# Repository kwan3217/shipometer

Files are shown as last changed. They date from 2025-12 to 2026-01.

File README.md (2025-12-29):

# Ansible for Shipometer

## Before first boot

Use `rpi-imager`. 

### Older `rpi-image` (<2.0.3)

1. Get an image that does Debian 12 (Bookworm) not Debian 13 (Trixie)
    * Raspberry Pi OS (Other) -> Raspberry Pi OS (Legacy, 64-bit) Lite
2. Eject MicroSD card from fluttershy and insert it in SD card reader attached to Celestia. 
3. Edit settings
    * General
      * [x] Set Hostname: `fluttershy`.local
      * [x] Set username and password:
         * Username: `chrisj`
         * Password: ******
      * [ ] Configure wireless LAN
      * [x] Set locale settings:
         * Time Zone: `America/Chicago` or as appropriate 
         * Keyboard layout: `us`
    * Services
       * [x] Enable SSH
          * ( ) Use password authentication
          * (*) Allow public-key authentication only
             * Set authorized_keys for `chrisj`: `<copy and paste from first line of /home/chrisj/.ssh/id_rsa.pub>` 
    * Options
      * [ ] Play sound when finished
      * [x] Eject media when finished
      * [ ] Enable telemetry

### Newer `rpi-image` (2.0.3)
1. Select the device type -- Raspberry Pi 5 for the current `fluttershy`
2. Raspberry Pi OS (Other) -> Raspberry Pi OS (Legacy, 64-bit) Lite
3. Insert and select the correct medium -- it is often already mounted
   as `/media/chrisj/devicename`. It is CRITICALLY IMPORTANT to get this right 
   -- check that the file size matches what is expected, and that it isn't
   one of your existing drives on the host filesystem. The check box [x] Exclude System Drives
   helps with this.
4. Set the hostname `fluttershy` not `fluttershy.local` or `fluttershy.kwansystems.org`
5. Set the capital city, time zone, and keyboard layout.
6. Set the user name `chrisj` and the password `<SECRET>`
7. Skip wifi for now
8. Enable SSH
   * ( ) Use Password Authentication
   * (*) Use public key authentication
      * Set authorized_keys for `chrisj`: `<copy and paste from first line of /home/chrisj/.ssh/id_rsa.pub>` 

### Write the image
Continue until the program writes the image on the card. Writing the image will take a few minutes.

## Boot new card in Fluttershy
Unmount and remove the card from the host and install it in a powered-off or red light Raspberry Pi 5.
Start it back up and wait for it to respond to pings. The router (Megumi)
knows Fluttershy's MAC address and will assign it the known IP `192.168.217.102`
and name `fluttershy.kwansystems.org`

## Run ansible
```
cd shipometer/ansible
ansible-playbook -i inventory.ini playbook.yml
```

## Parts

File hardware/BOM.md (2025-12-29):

# Shipometer Hardware Bill of Materials

| Qty | Description | Part Number / Spec | Notes / Link | Approx. Unit Cost (bulk) |
|-----|---|---|---|---|
| 1 | Raspberry Pi 5 8GB | Raspberry Pi 5 | Official board - fluttershy | - |
| 1 | dAISy 2+ AIS USB receiver | dAISy 2+ | USB dongle, black aluminum enclosure typical | - |
| 1 | FlightAware Pro Stick Plus ADS-B receiver | FA-PROSTICKPLUS | Or equivalent USB dongle | - |
| 1 | Sparkfun breakout for u-blox ZED-F9R GPS module (with IMU) | ZED-F9R | UART + PPS wired to GPIO | Datasheet: https://www.u-blox.com/en/product/zed-f9r-module |
| 1 | Bosch BME280 sensor breakout | BME280 | SPI on GPIO | Datasheet: https://www.bosch-sensortec.com/products/environmental-sensors/humidity-sensors-bme280/ |
| 1 | Optional cooling fan (for enclosed case) | CoolCox CC3007H05S (or equiv.) | 30x30x7mm, 5V, 4-pin JST-SH 1.0mm pitch (PWM + tach), ~8000 RPM max, 2.79 CFM | Matches official Pi 5 case fan; Datasheet: https://www.coolcox.com/products/pdf/CC3007.pdf |
| 4 | M2.5 brass/hex standoffs (various lengths, e.g., 11mm + 20mm) | Generic M2.5 F/F or M/F | For Pi mounting + HAT spacing | Jellybean; e.g., from assortment kits |
| 8-16| M2.5 screws (e.g., 6-12mm pan head) | Generic M2.5 stainless | For securing board, lid, standoffs | - |
| 4 | Silicone feet or bumpers | Generic 8-10mm dia. | Anti-slip for desk/cabin mount | - |
| 1 | Custom 3D-printed case | Your OpenSCAD design | PLA/PETG/ABS recommended for durability | - |
| Misc| Antennas (GPS mushroom, 1090MHz ADS-B, 161-162MHz AIS) | Various | Roof-mounted when landlocked | - |
| Misc| Cables (USB extensions, UART jumpers, PPS wire) | - | As needed for clean routing | - |

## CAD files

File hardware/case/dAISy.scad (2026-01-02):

MM=1;
INCH=25.4*MM;



module daisy() {
  board_w=3.0*INCH;
  board_d=1.95*INCH;
  board_h=1.6*MM;
  module daisy_main_board() {
    hole_r=3.0*MM/2;
    // clearances between edge of hole and edge of board measured by outside caliper
    hole_x1=        2.5*MM;
    hole_x2=board_w-2.6*MM;
    hole_y1=        2.7*MM;
    hole_y2=board_d-2.0*MM;
    color("green")
    translate([0,0,-board_h])
    difference() {
      // substrate
      cube([board_w,board_d,board_h]);
      // mounting holes
      translate([hole_x1+hole_r,hole_y1+hole_r,-1*MM])
      cylinder(h=2*MM+board_h,r=hole_r,$fn=24);
      translate([hole_x2-hole_r,hole_y1+hole_r,-1*MM])
      cylinder(h=2*MM+board_h,r=hole_r,$fn=24);
      translate([hole_x1+hole_r,hole_y2-hole_r,-1*MM])
      cylinder(h=2*MM+board_h,r=hole_r,$fn=24);
      translate([hole_x2-hole_r,hole_y2-hole_r,-1*MM])
      cylinder(h=2*MM+board_h,r=hole_r,$fn=24);
    }
  }
  daisy_main_board();
  module bnc() {
    cube_w=14.5*MM;
    cube_d=14.5*MM;
    cube_h=17.1*MM-board_h;
    color("#c0c0c0")
    union() {
      cube([cube_w,cube_d,cube_h]);
      // thread
      thread_r=0.48*INCH/2;
      thread_d=23.2*MM-cube_d;
      thread_square=10.7*MM;
      intersection() {
        translate([cube_w/2,1*MM,15.3*MM-board_h-thread_r])
        rotate([90,0,0])
        cylinder(h=thread_d+1*MM,r=thread_r);
        translate([cube_w/2,1*MM,15.3*MM-board_h-thread_r])
        cube([thread_square,20*MM,thread_square],center=true);
      }
      // barrel
      barrel_r=0.37*INCH/2;
      barrel_d=35.2*MM-cube_d-thread_d;
      translate([cube_w/2,1*MM-thread_d,15.3*MM-board_h-thread_r])
      rotate([90,0,0])
      cylinder(h=barrel_d+1*MM,r=barrel_r);
    }
  }
  translate([55*MM,0.5*MM,0*MM])
  bnc();
}

daisy();

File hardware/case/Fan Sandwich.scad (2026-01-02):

include<kwan_primitives.scad>

EPS=0.5*MM;

M5_hole_MM=3.0;

module fan_sandwich_bottom_plate() {
difference() {
//main body
translate([0,0,0])
rounded_cube((58+7)*MM,56*MM,2*MM);

//corner holes
translate([3.5*MM,3.5*MM,-1*MM])
cylinder(5,M5_hole_MM/2,M5_hole_MM/2,$fn=24);
translate([(3.5+58)*MM,3.5*MM,-1])
cylinder(5,M5_hole_MM/2,M5_hole_MM/2,$fn=24);
translate([3.5,(3.5+49)*MM,-1])
cylinder(5,M5_hole_MM/2,M5_hole_MM/2,$fn=24);
translate([(3.5+58)*MM,(3.5+49)*MM,-1*MM])
cylinder(5,M5_hole_MM/2,M5_hole_MM/2,$fn=24);

//GPIO hole
translate([(3.5+29)*MM,(3.5+49)*MM,1*MM])
cube([2*INCH+EPS*2,0.2*INCH+EPS,4*MM],center=true);
translate([(3.5+29)*MM-1*INCH+15*MM,(56/2)*MM,-1])
cylinder(h=4*MM,r1=28/2*MM,r2=28/2*MM);
}
}

module fan_hook() {
  translate([-2*MM,-2.5*MM,-1*MM])
  difference(){
  cube([3*MM,5*MM,10*MM+EPS*2]);
  translate([2*MM,-1*MM,-1*MM])
  cube([5*MM,7*MM,9*MM+EPS*2]);
  color("blue")
  translate([0*MM,-1*MM,12*MM])
  rotate([0,45,0])
  cube([5*MM,7*MM,5*MM]);
  }
}

module fan_hole() {
translate([0,0,(7.7/2+1)*MM])
rotate([180,0,0])
union(){
cylinder(h=(7.7/2+1)*MM,r1=4.5*MM/2,r2=4.5*MM/2,$fn=24);
cylinder(h=(7.7+2)*MM,r1=3.2*MM/2,r2=3.2*MM/2,$fn=24);
}
}

module fan() {
  difference() {
    translate([-30.4/2*MM,-30.4/2*MM,-7.7/2*MM])
    rounded_cube(30.4*MM,30.4*MM,7.7*MM,r=3.2*MM);
    
    translate([0,0,-(7.7+1)/2*MM])
    cylinder(h=9.7*MM,r1=27/2*MM,r2=27/2*MM);

    translate([-12*MM,-12*MM,0])
    fan_hole();
    translate([12*MM,-12*MM,0])
    fan_hole();
    translate([-12*MM,12*MM,0])
    fan_hole();
    translate([12*MM,12*MM,0])
    fan_hole();
  }
}

module fan_pegs() {
    translate([-12*MM,-12*MM,-2*MM])
    cylinder(h=3*MM,r=(4*MM-EPS)/2,$fn=24);
    translate([12*MM,-12*MM,-2*MM])
    cylinder(h=3*MM,r=(4*MM-EPS)/2,$fn=24);
    translate([-12*MM,12*MM,-2*MM])
    cylinder(h=3*MM,r=(4*MM-EPS)/2,$fn=24);
    translate([12*MM,12*MM,-2*MM])
    cylinder(h=3*MM,r=(4*MM-EPS)/2,$fn=24);
}

module fan_sandwich() {
  union() {
  fan_sandwich_bottom_plate();

  translate([(3.5+29)*MM-1*INCH+15*MM,(56/2)*MM,0])color("orange")fan_pegs();
    translate([(3.5+29)*MM-1*INCH+15*MM,(56/2)*MM+15*MM,0])
    rotate([0,0,-90])
    rotate([180,0,0])
    fan_hook();
  }
}

module placed_fan() {
  translate([(3.5+29)*MM-1*INCH+15*MM,(56/2)*MM,-7.7/2*MM])
  color("black")
  fan();
}

// Uncomment this if you want to actually print it
//rotate([180,0,0]) fan_sandwich();

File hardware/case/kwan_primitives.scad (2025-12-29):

INCH=25.4; // multiply a measurement in inches by this to get mm
MM=1; // for completeness and readability


module rounded_cube(l,w,h,r=2*MM) {
  union() {
    translate([r,0,0])
    cube([l-2*r,w,h]);
    translate([0,2,0])
    cube([l,w-2*r,h]);
    translate([r,r,0])
    cylinder(h=h,r1=r,r2=r,$fn=36);
    translate([r,w-r,0])
    cylinder(h=h,r1=r,r2=r,$fn=36);
    translate([l-r,r,0])
    cylinder(h=h,r1=r,r2=r,$fn=36);
    translate([l-r,w-r,0])
    cylinder(h=h,r1=r,r2=r,$fn=36);
  }
}

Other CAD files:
hardware/case/ShipometerCase.scad
hardware/case/test_nut.scad
hardware/case/zed-f9r.scad
hardware/case/zed_f9r_case.scad

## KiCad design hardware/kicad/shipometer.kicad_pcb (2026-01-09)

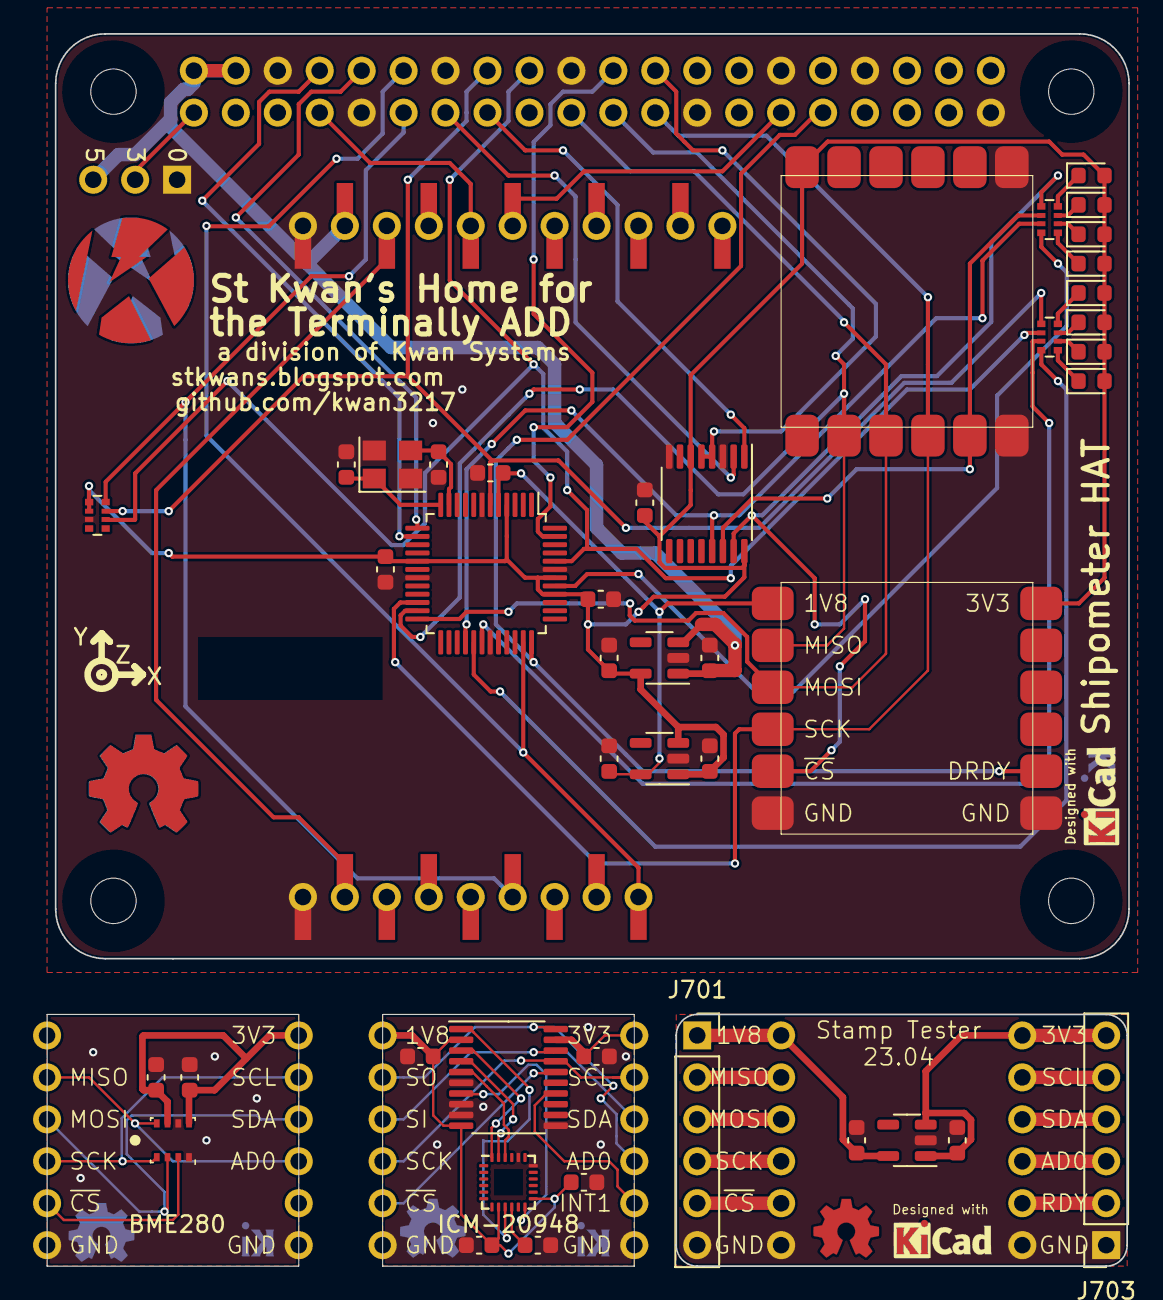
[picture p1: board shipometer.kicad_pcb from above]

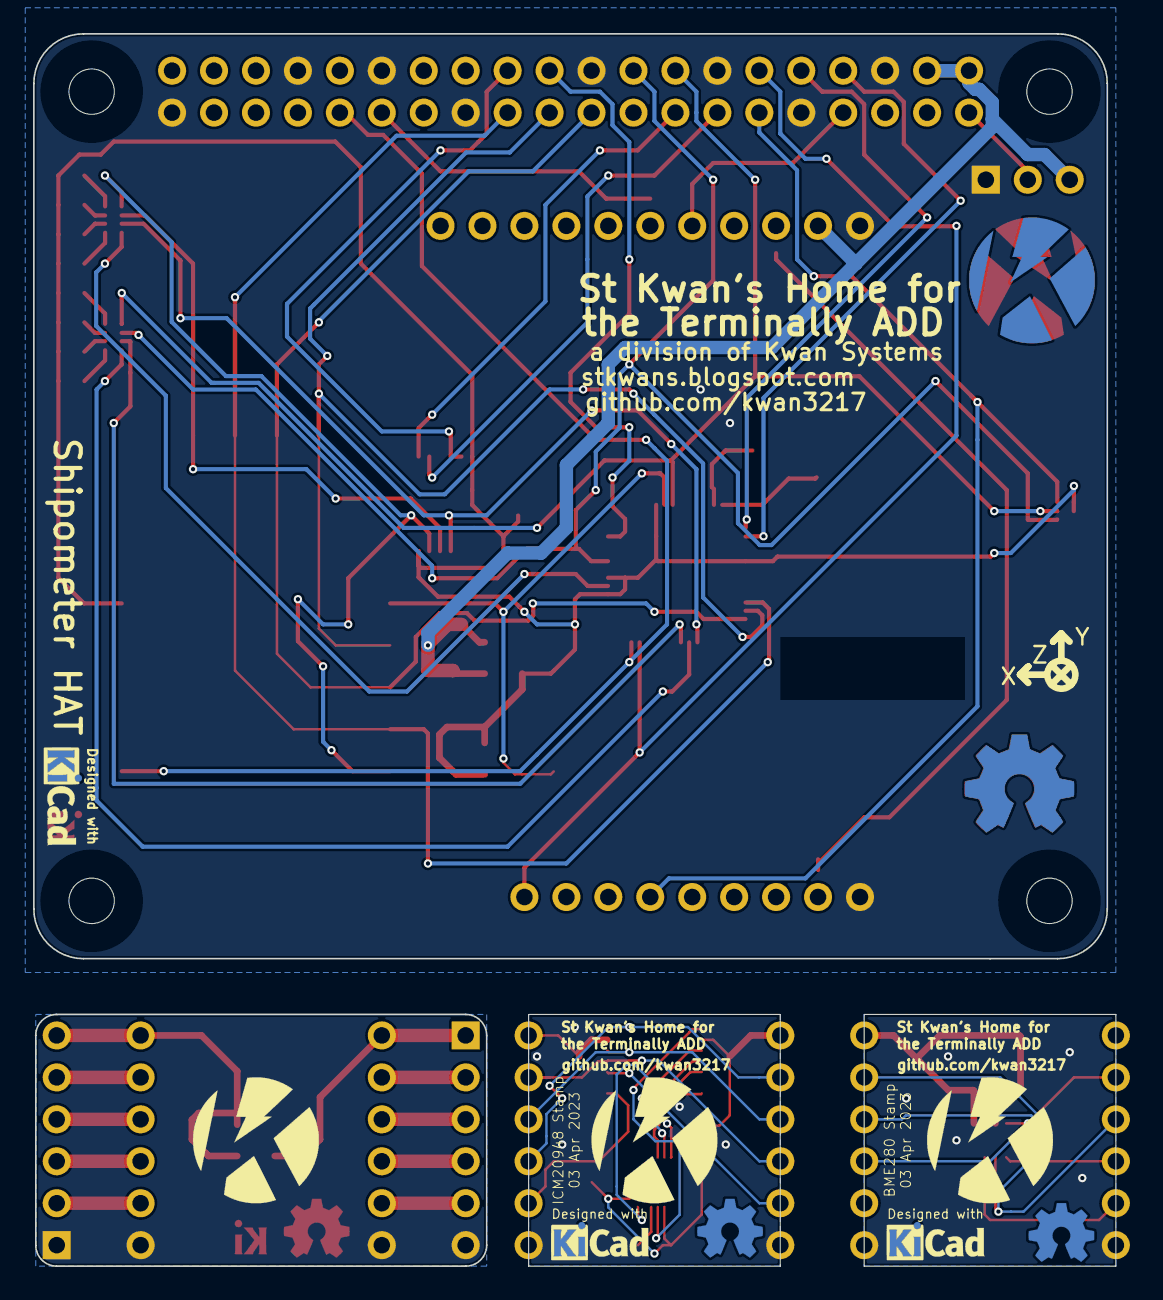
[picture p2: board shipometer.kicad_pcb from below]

Board: 2 copper layers, 65.5 x 74.6 mm, 66 parts (10 on the bottom side), 69 nets.

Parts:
C116, C206, C208, C401, C405, C501, C505, C605, C617, C640, C801, C805: 1uF; C_0603_1608Metric
C302, C308, C310, C313, C319: 100nF; C_0603_1608Metric
C611, C612: 22pF; C_0603_1608Metric
D101, D103, D104: White; LED_0603_1608Metric
D106: Blue; LED_0603_1608Metric
D129: Red; LED_0603_1608Metric
D130: Green; LED_0603_1608Metric
D141, D144: Yellow; LED_0603_1608Metric
G101: Axis
G102, G105: KwanSystems; StKwansSoldermask
G103, G107, G202, G302, G702: Designed with; Symbol_KiCAD-Logo_CopperAndSilkScreenTop_small
G104, G106: OSHW; OSHW-Symbol_6.7x6mm_SolderMask
G201, G301, G701: github.com/kwan3217; KWAN_CIRCLE
G203, G303, G703: OSHW; OSHW-Symbol_4x3.6mm_SolderMask
J101: Raspberry_Pi_40; PiHAT_NoSlot_Narrow
J102: Conn_01x03; PinHeader_1x03_P2.54mm_Horizontal
J104: ICM20948; StampPad
J105: BME280; StampPad
J106: ZED-F9R
J201, J301: Stamp
J701, J703: Conn_01x06_Pin; PinSocket_1x06_P2.54mm_Vertical
J702, J704: Conn_01x06_Pin; PinHeader_1x06_P2.54mm_Vertical
R101, R102: 330; R_Array_Convex_4x0402
R103: 10k; R_Array_Convex_4x0402
U102: 74LS138; TSSOP-16_4.4x5mm_P0.65mm
U201: BME280; Bosch_LGA-8_2.5x2.5mm_P0.65mm_ClockwisePinNumbering
U301: ICM-20948; InvenSense_QFN-24_3x3mm_P0.4mm
U302: TXS0108EPW; TSSOP-20_4.4x6.5mm_P0.65mm
U401: TCR2EF 3.3V; SOT-23-5
U501, U801: TCR2EF 1.8V; SOT-23-5
U601: LPC210x; LQFP-48_7x7mm_P0.5mm
Y601: 12MHz; Crystal_SMD_Abracon_ABM8G-4Pin_3.2x2.5mm

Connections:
3V3: J106.3 (3V3), J106.13 (3V3)
+1V8: C505.1, C605.1, J104.1 (1V8), U501.5 (OUT), U601.5 (VDD(1V8))
+3.3VP: J101.1 (3V3), J102.2
+3V3: C116.1, C405.1, C501.1, C617.1, C640.1, D101.2 (A), D103.2 (A), D104.2 (A), D106.2 (A), D129.2 (A), D130.2 (A), D141.2 (A), D144.2 (A), J104.12 (3V3), J105.12 (3V3), R103.1 (4), R103.2 (4), U102.6 (E3), U102.16 (VCC), U401.5 (OUT), U501.1 (IN), U501.3 (EN), U601.4 (VBAT), U601.17 (VDD(3V3)), U601.40 (VDD(3V3)), U601.42 (VDDA)
+5V: C401.1, J101.2 (5V), J101.4 (5V), J102.3, J106.2 (5V), U401.1 (IN), U401.3 (EN)
/BOOTSTRAP-: D144.1 (K), R102.7 (5)
/CS_A0: J101.15 (GPIO22_(GEN3)), U102.1 (A0)
/CS_A1: J101.13 (GPIO27_(GEN2)), U102.2 (A1)
/DRDY-: D129.1 (K), R102.5
/DRDY_6D: J101.31 (GPIO6), J104.8 (DRDY), U601.36 ((CTS1/CAP1.1/AD0.4)P0.11)
/DRDY_MAG: J101.22 (GPIO25_(GEN6)), U601.47 ((CAP1.2/SCL1)P0.17)
/DRDY_MAG-: D130.1 (K), R102.6 (5)
/GPS_RX: J101.7 ((TX3)_GPIO4), J106.5 (RX/MOSI)
/GPS_TX: J101.29 ((RX3)_GPIO5), J106.6 (TX/MISO)
/GPS_~RESET: J101.11 (GPIO17_(GEN0)), J106.17 (~RESET), R103.8 (5)
/IMU/INT1_1V8: U301.12 (INT1), U302.7 (A6)
/IMU/INT1_3V3: J301.8 (INT1), U302.14 (B6)
/IMU/MISO_1V8: U301.9 (SDO/AD0), U302.1 (A1)
/IMU/MISO_3V3: J301.2 (MISO), J301.9 (AD0), U302.20 (B1)
/IMU/MOSI_1V8: U301.24 (SDA/SDI), U302.3 (A2)
/IMU/MOSI_3V3: J301.3 (MOSI), J301.10 (SDA), U302.18 (B2)
/IMU/Q_1V8: C302.1, C308.1, C313.1, J301.1 (1V8), U301.8 (VDDIO), U301.13 (VDD), U302.2 (VCCA), U302.10 (OE)
/IMU/Q_3V3: C319.1, J301.12 (3V3), U302.19 (VCCB)
/IMU/Q_GND: C302.2, C308.2, C310.2, C313.2, C319.2, J301.6 (GND), J301.7 (GND), U301.18 (GND), U301.20 (GND), U302.6 (A5), U302.8 (A7), U302.9 (A8), U302.11 (GND)
/IMU/SCK_1V8: U301.23 (SCL/SCLK), U302.4 (A3)
/IMU/SCK_3V3: J301.4 (SCK), J301.11 (SCL), U302.17 (B3)
/IMU/~CS_1V8: U301.22 (~CS), U302.5 (A4)
/IMU/~CS_3V3: J301.5 (~CS), U302.16 (B4)
/LPC_RESET-: D106.1 (K), R102.8 (5)
/LPC_RX: J101.8 ((TX0)_GPIO14), U601.14 ((RXD0/MAT3.2)P0.1)
/LPC_TX: J101.10 ((RX0)_GPIO15), U601.13 ((TXD0/MAT3.1)P0.0)
/LPC_~BOOTSTRAP: J101.18 (GPIO24_(GEN5)), R102.2 (4), R103.6 (5), U601.44 ((DCD1/SCK1/EINT1)P0.14)
/LPC_~RESET: J101.16 (GPIO23_(GEN4)), R102.1 (4), R103.7 (5), U601.6 (~RST)
/MISO_3V3: J101.21 ((SPI_MISO)_GPIO9), J104.2 (MISO), J105.2 (MISO), U601.23 ((MISO0/MAT0.1)P0.5)
/MOSI_3V3: J101.19 ((SPI_MOSI)_GPIO10), J104.3 (MOSI), J105.3 (MOSI), U601.24 ((MOSI0/CAP0.2)P0.6)
/PPS: J101.12 (GPIO18_(GEN1)), J106.20 (PPS), U601.35 ((RTS1/CAP1.0/AD0.3)P0.10)
/PPS-: D141.1 (K), R101.5
/Pressure/MISO: J201.2 (MISO), J201.9 (AD0), U201.5 (SDO)
/Pressure/MOSI: J201.3 (MOSI), J201.10 (SDA), U201.3 (SDI)
/Pressure/Q_3V3: C206.1, C208.1, J201.12 (3V3), U201.6 (VDDIO), U201.8 (VDD)
/Pressure/Q_GND: C206.2, C208.2, J201.6 (GND), J201.7 (GND), U201.1 (GND), U201.7 (GND)
/Pressure/SCK: J201.4 (SCK), J201.11 (SCL), U201.4 (SCK)
/Pressure/~CS: J201.5 (~CS), U201.2 (CSB)
/SCK_3V3: J101.23 ((SPI_SCLK)_GPIO11), J104.4 (SCK), J105.4 (SCK), U601.22 ((SCK0/CAP0.1)P0.4)
/Stamp Tester/Q_1V8: C805.1, J701.1, J702.1, U801.5 (OUT)
/Stamp Tester/Q_3V3: C801.1, J703.6, J704.6, U801.1 (IN), U801.3 (EN)
/Stamp Tester/Q_AD0: J703.3, J704.3
/Stamp Tester/Q_DRDY: J703.2, J704.2
/Stamp Tester/Q_GND: C801.2, C805.2, J701.6, J702.6, J703.1, J704.1, U801.2 (GND)
/Stamp Tester/Q_MISO: J701.2, J702.2
/Stamp Tester/Q_MOSI: J701.3, J702.3
/Stamp Tester/Q_SCK: J701.4, J702.4
/Stamp Tester/Q_SCL: J703.5, J704.5
/Stamp Tester/Q_SDA: J703.4, J704.4
/Stamp Tester/Q_~CS: J701.5, J702.5
/Timer/XTAL1: C611.2, U601.11 (XTAL1), Y601.3
/Timer/XTAL2: C612.2, U601.12 (XTAL2), Y601.1
/~CE0: J101.24 ((~SPI_CE0)_GPIO8), U102.4 (E1), U102.5 (E2)
/~CS_6D: J104.5 (~CS), R101.1 (4), U102.15 (O0)
/~CS_6D+: D101.1 (K), R101.8 (5)
/~CS_LPC: R101.3 (4), U102.13 (O2), U601.28 ((SSEL0/MAT2.0)P0.7)
/~CS_LPC+: D104.1 (K), R101.6 (5)
/~CS_PRES: J105.5 (~CS), R101.2 (4), U102.14 (O1)
/~CS_PRES+: D103.1 (K), R101.7 (5)
/~DRDY_6D_ECHO: R102.4, U601.29 ((TXD1/MAT2.1)P0.8)
/~DRDY_MAG_ECHO: R102.3 (4), U601.30 ((RXD1/MAT2.2)P0.9)
/~PPS_ECHO: R101.4, U601.41 ((DTR1/MAT1.1)P0.13)
GND: C116.2, C401.2, C405.2, C501.2, C505.2, C605.2, C611.1, C612.1, C617.2, C640.2, J101.6 (GND), J101.9 (GND), J101.14 (GND), J101.20 (GND), J101.25 (GND), J101.30 (GND), J101.34 (GND), J101.39 (GND), J102.1, J104.6 (GND), J104.7 (GND), J105.6 (GND), J105.7 (GND), J106.1 (GND), J106.12 (GND), R103.3 (4), U102.3 (A2), U102.8 (GND), U401.2 (GND), U501.2 (GND), U601.7 (VSS), U601.19 (VSS), U601.31 (VSSA), U601.43 (VSS), Y601.2, Y601.4
unnamed: C310.1, U301.10 (REGOUT)

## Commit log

2025-12-29 Make sure gpsd.socket.d folder exists
2025-12-29 Reference Ralf Lange's RaspberryPiCases project to pull in mechanical scad for Raspberry Pi 5.
2025-12-29 Added Shipometer 23.04 as built
    [BME280 stamp.kicad_sch, Demo.kicad_sch, ICM20948 stamp.kicad_sch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]
2025-12-29 Removed separate board files -- only unified project is included.
    [shipometer_bmp_stamp.kicad_pcb, shipometer_hat.kicad_pcb, shipometer_hat.kicad_sch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]
2025-12-29 Imported shipometer hat 23.04 as built, updated to Kicad 9
    [BME280 stamp.kicad_sch, Demo.kicad_sch, ICM20948 stamp.kicad_sch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]
2025-12-29 Add fan sandwich at v3. This is the version that is currently (2025-12-29) in the Fluttershy stack.
    [Fan Sandwich.scad]
2025-12-29 Add scad files for zed_f9r and its own case, shipometer, and factored-out primitives.
    [Fan Sandwich.scad, ShipometerCase.scad, kwan_primitives.scad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]
2026-01-02 Add initial scad file for dAISy2+
    [dAISy.scad]
2026-01-02 Add isolated file for fan sandwich
    [Fan Sandwich.scad]
2026-01-02 Include more of the fan stack
    [ShipometerCase.scad]
2026-01-09 Change version number to 23.04.1 reflecting the green-wire fix
    [shipometer.kicad_pcb]
